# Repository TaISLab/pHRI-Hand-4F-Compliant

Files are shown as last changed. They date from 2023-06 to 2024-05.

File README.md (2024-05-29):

# pHRI-Hand-4F-Compliant

En este repositorio se encuentran los archivos relativos a la interacción fisica robot-humano. Por tanto, se encuentran ficheros de la garra subactuada de cuatro dedos con muelles en los eslabones

Overview of the gripper
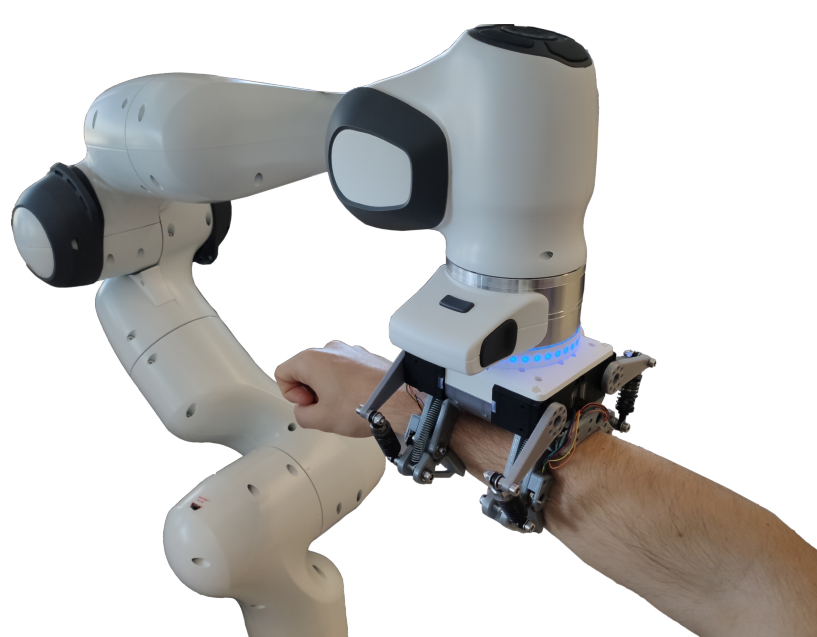
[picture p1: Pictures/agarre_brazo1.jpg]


Passive compliance
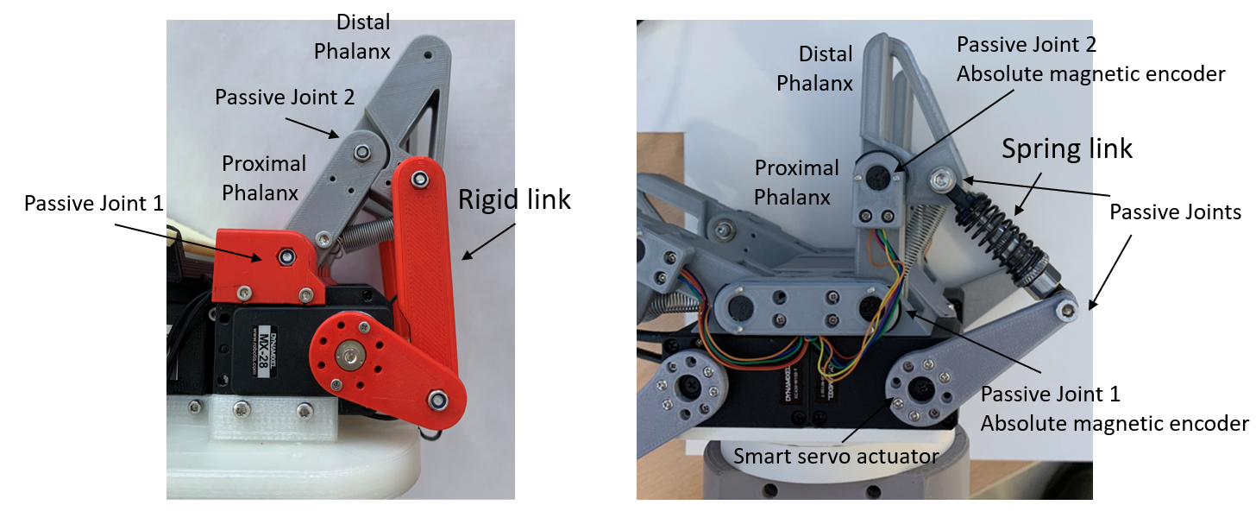
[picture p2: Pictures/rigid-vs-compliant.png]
Rigid vs flexible Links


También se encuentran los codigos fuente del control compartido.

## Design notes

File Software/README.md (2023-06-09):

# underactuated-gripper

En este repositorio se encuentran todos los ficheros relativos a la garra subactuada de cuatro dedos con eslabón elástico. El repositorio está organizado de la siguiente forma:

- **Carpeta arduino.** Contiene los codigos fuente de los dispositivos implicados en la garra. Contiene los scripts del sensor de fuerzas cilíndrico rojo basado en galgas extensiométricas y el sensor HX711 (Lectura\_hx711), y de control de la garra (lecturaMotorEncoder\_V8).

- **Carpeta Data.** Contiene los datos de los experimentos realizados con la garra. Los datos se encuentran separados por carpetas, atendiendo al tipo de experimento con el que se han obtenido.

- **Carpeta grippers\_conf.** Contiene los parametros de las garras subactuada de cuatro dedos y rolling fingers en formato JSON. Se pueden cargar desde la interfaz del robot para hacer el cambio de efector final. 

- **Carpeta ros.** Contiene el paquete ROS (version melodic) desarrollado para el control y la monitorización de la garra desde dicho OS. 

- **Carpeta scripts.** Contiene los programas de matlab para el computo del modelo kinetostatico de los dedos, así como los scripts para el procesamiento de los datos de los experimentos y su representación gráfica.

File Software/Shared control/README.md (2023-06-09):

# Requisitos del Shared control 

Para el funcionamiento del shared control es necesario el uso de la librería libfranka y un sistema operativo de tiempo real (en la página web de franka emika se explica como instalarlo, añadir enlace al tutorial), un robot franka emika (he implementado el control directamente sobre la API de este robot), el paquete matlogger para recopilación de datos (añadir link al repo de matlogger).

La carpeta franka\_ros contiene el paquete de ros de franka emika con todos los controladores que he desarrollado (es la versión del robot FR3), mas concretamente es dentro de la carpeta "franka\_example\_controllers" donde se encuentran todos los controladores que he desarrollado (a parte de los que vienen en el paquete por defecto). Es importante que el paquete "subact\_gripper" se encuentre en el mismo workspace de ros que el paquete "franka\_ros", ya que se requiere el uso de la garra en algunos controladores.

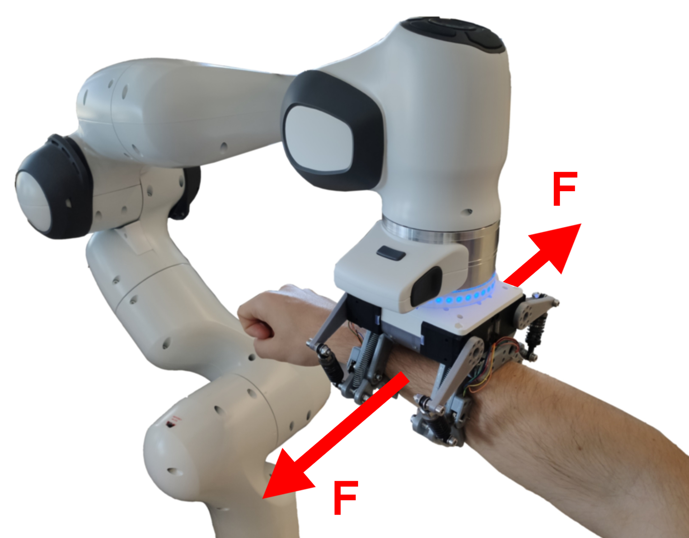
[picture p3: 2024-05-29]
Pictures/agarre_brazo1_F.jpg

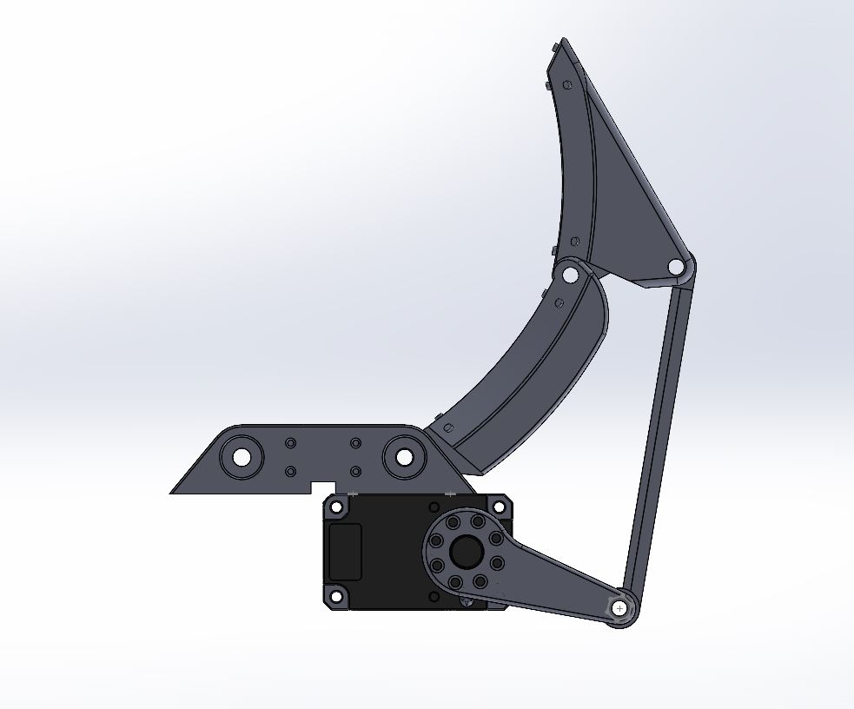
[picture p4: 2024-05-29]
CAD/Mano2.JPG

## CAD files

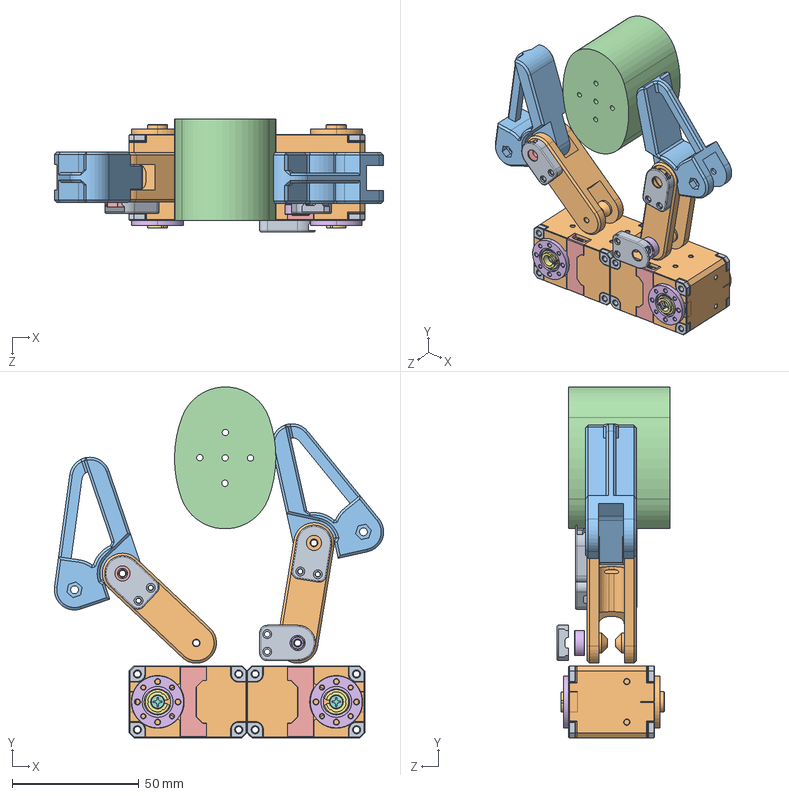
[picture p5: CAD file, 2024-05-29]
CAD/mano2.SLDASM
130.0 x 138.5 x 44.5 mm
potBASE x 3
DC11_A01_DUMMY.stp x 2
DX124_SCREW-COVER.stp x 2
B3B-EH.stp x 4
DC11_A01_CASE_CVR_DUMMY.stp x 2
DC11_A01_IDLER_DUMMY.stp x 2
DC11_A01_IDLER_CAP_DUMMY.stp x 2
DC11_A01_IDLER_SCREW.stp x 2
DC11_A01_SPACER_DUMMY.stp x 16
Palo1 x 2
pico20-ligero x 2
potenciometro
3x10x4 x 2

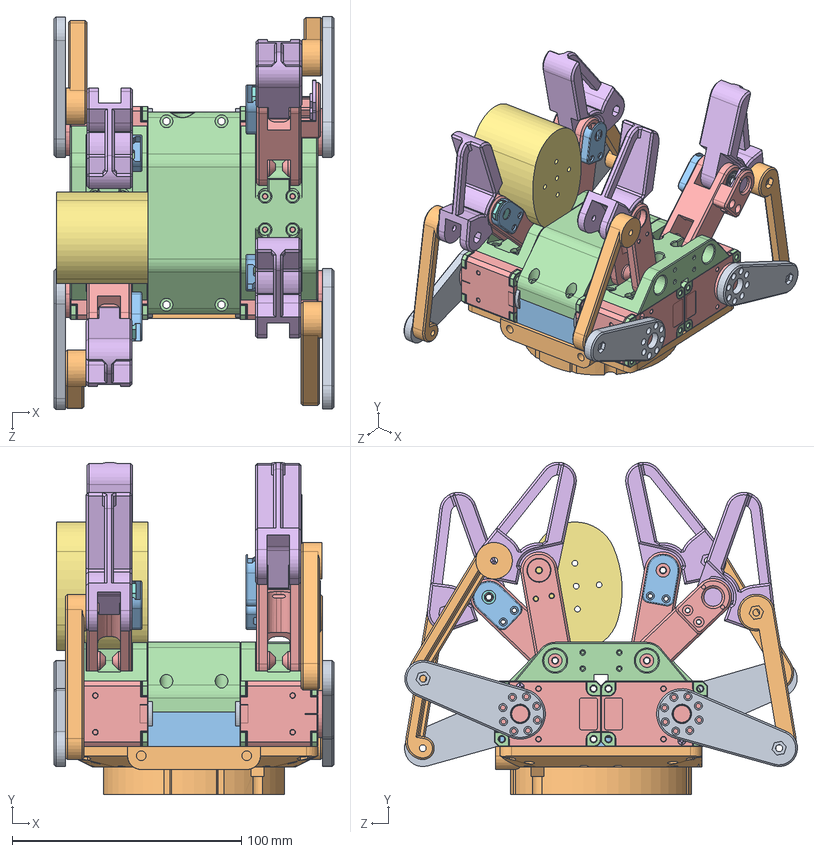
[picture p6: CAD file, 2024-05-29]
CAD/mano4.SLDASM
122.0 x 145.0 x 171.4 mm
biela servo 45 x 4
Palo2 x 4
potBASE x 6
base4 x 2
DC11_A01_DUMMY.stp x 4
DX124_SCREW-COVER.stp x 4
B3B-EH.stp x 8
DC11_A01_CASE_CVR_DUMMY.stp x 4
DC11_A01_IDLER_DUMMY.stp x 4
DC11_A01_IDLER_CAP_DUMMY.stp x 4
DC11_A01_IDLER_SCREW.stp x 4
DC11_A01_SPACER_DUMMY.stp x 32
Palo1 x 4
pico20-ligero x 4
potenciometro x 2
3x10x4 x 4
base-robot-4
module control
module-chepa
soporteencodersimple
as5048a

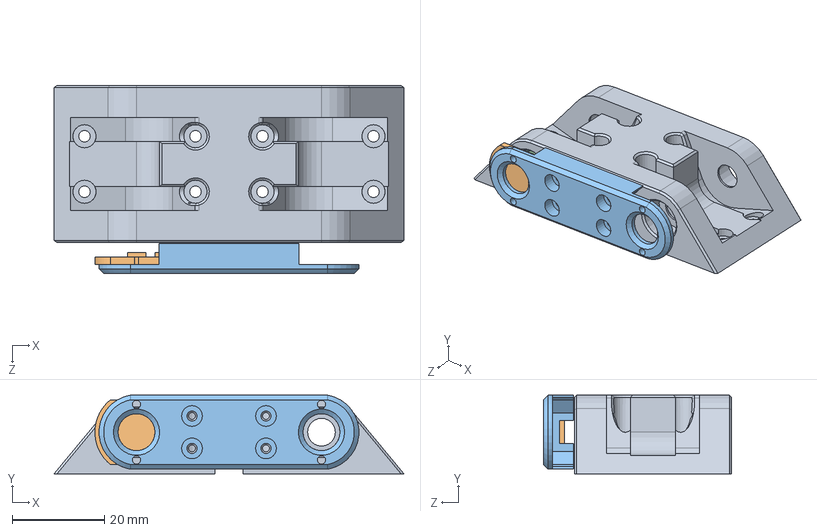
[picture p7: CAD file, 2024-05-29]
CAD/ensamblebasedosdedos.SLDASM
75.7 x 17.0 x 40.7 mm
base4
as5048a
soporteencoder
3x10x4

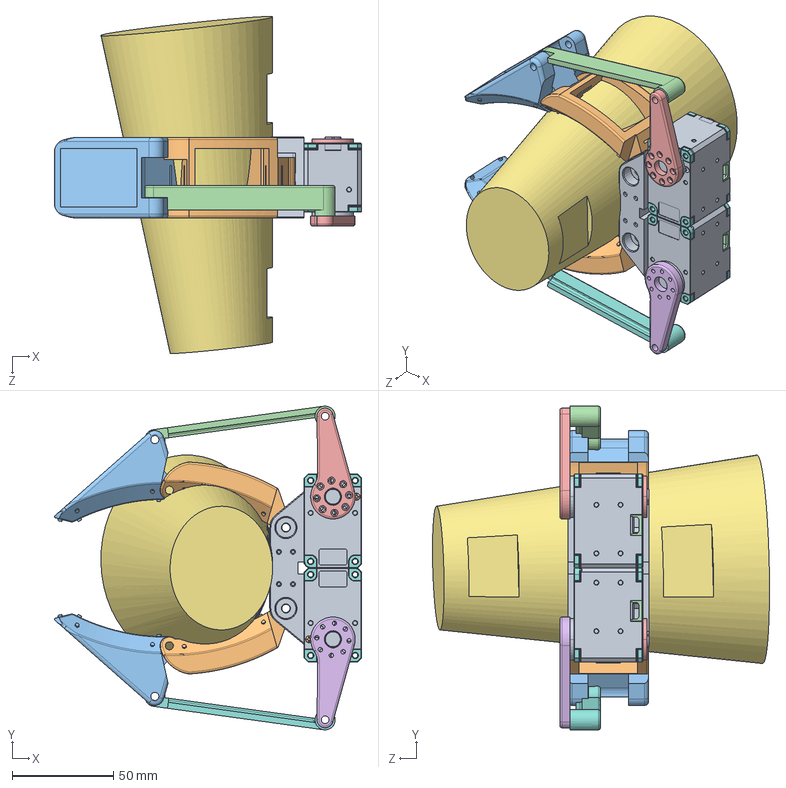
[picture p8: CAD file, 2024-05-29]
CAD/Mano2_mod - antebrazo.SLDASM
152.1 x 160.1 x 166.7 mm
DC11_A01_DUMMY.stp x 2
DX124_SCREW-COVER.stp x 2
B3B-EH.stp x 4
DC11_A01_CASE_CVR_DUMMY.stp x 2
DC11_A01_IDLER_DUMMY.stp x 2
DC11_A01_IDLER_CAP_DUMMY.stp x 2
DC11_A01_IDLER_SCREW.stp x 2
DC11_A01_SPACER_DUMMY.stp x 16
base4_mod
phalanx1_v8 x 2
phalanx2_v7 x 2
Palo2 85mm
Biela Servo 40 mm
Biela Servo 40 mm - left
Modelo_brazo_notwist
Palo2 85mm - left

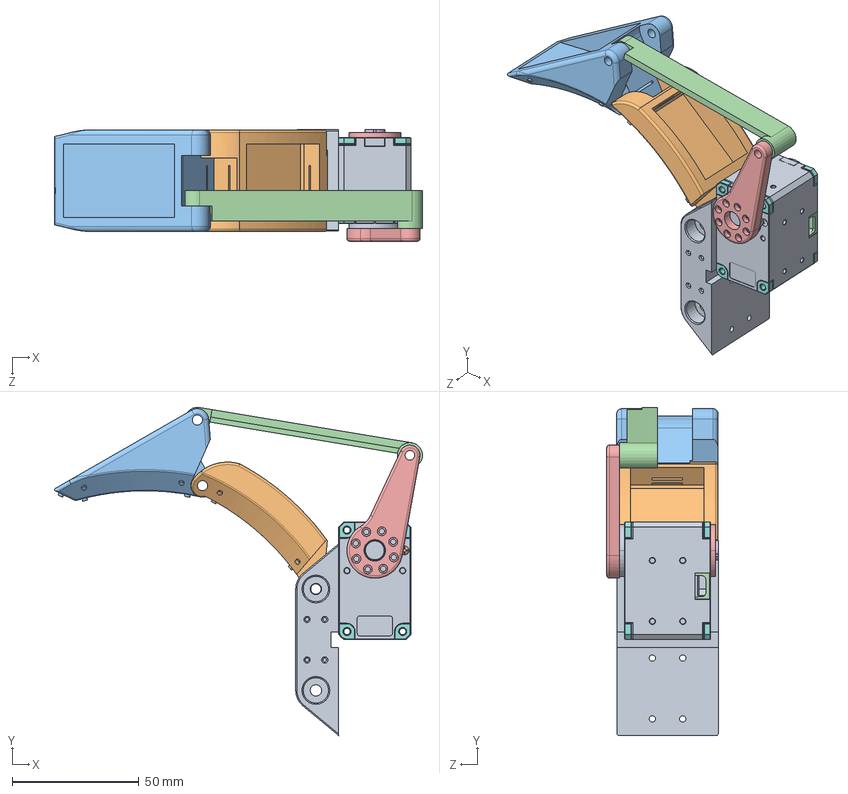
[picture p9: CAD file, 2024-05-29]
CAD/Mano2_mod.SLDASM
145.2 x 129.5 x 44.0 mm
DC11_A01_DUMMY.stp
DX124_SCREW-COVER.stp
B3B-EH.stp x 2
DC11_A01_CASE_CVR_DUMMY.stp
DC11_A01_IDLER_DUMMY.stp
DC11_A01_IDLER_CAP_DUMMY.stp
DC11_A01_IDLER_SCREW.stp
DC11_A01_SPACER_DUMMY.stp x 8
base4_mod
phalanx1_v8
phalanx2_v7
Palo2 85mm
Biela Servo 40 mm

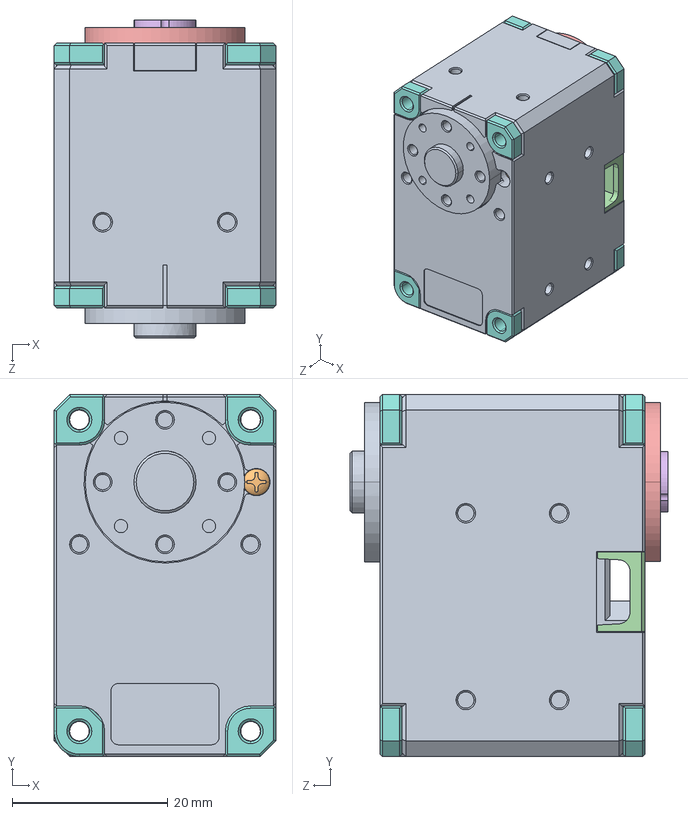
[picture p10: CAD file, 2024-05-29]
CAD/XL-430_new.SLDASM
28.5 x 46.5 x 40.9 mm
DC11_A01_DUMMY.stp
DX124_SCREW-COVER.stp
B3B-EH.stp x 2
DC11_A01_CASE_CVR_DUMMY.stp
DC11_A01_IDLER_DUMMY.stp
DC11_A01_IDLER_CAP_DUMMY.stp
DC11_A01_IDLER_SCREW.stp
DC11_A01_SPACER_DUMMY.stp x 8

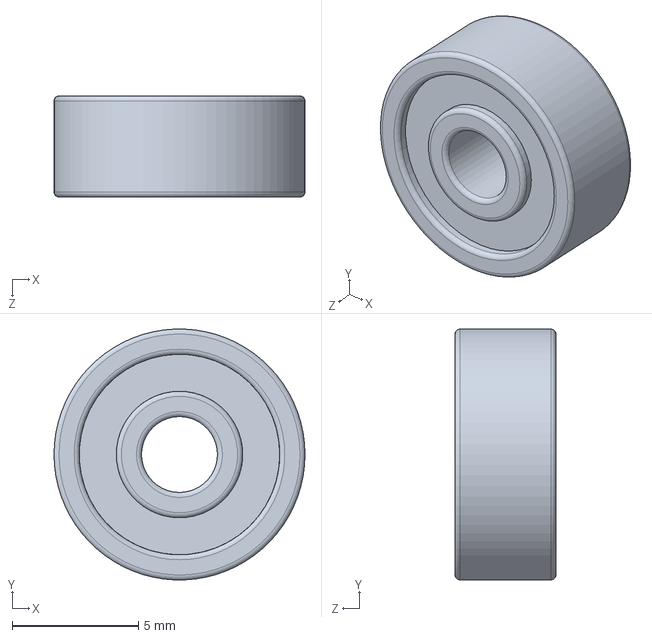
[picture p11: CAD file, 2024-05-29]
CAD/bearings/3x10x4.SLDPRT
9.93 x 9.92 x 4.00 mm

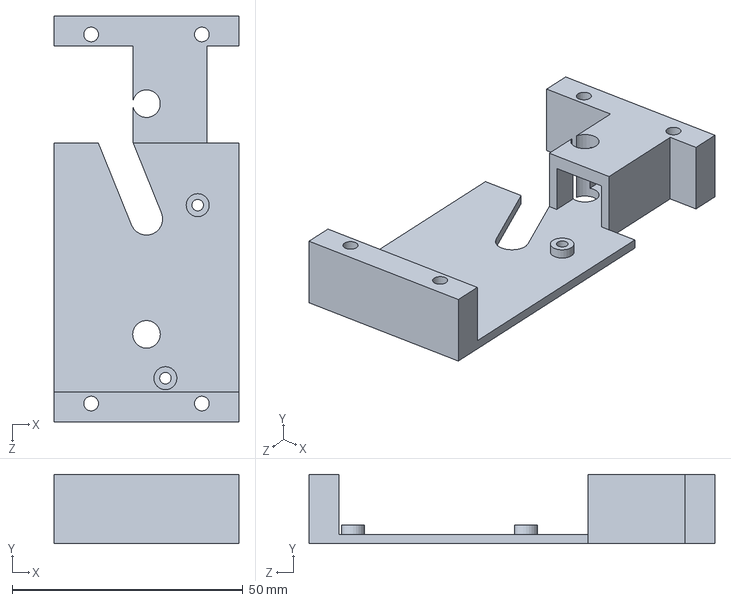
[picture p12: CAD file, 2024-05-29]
CAD/module control.SLDPRT
40.0 x 15.0 x 88.0 mm

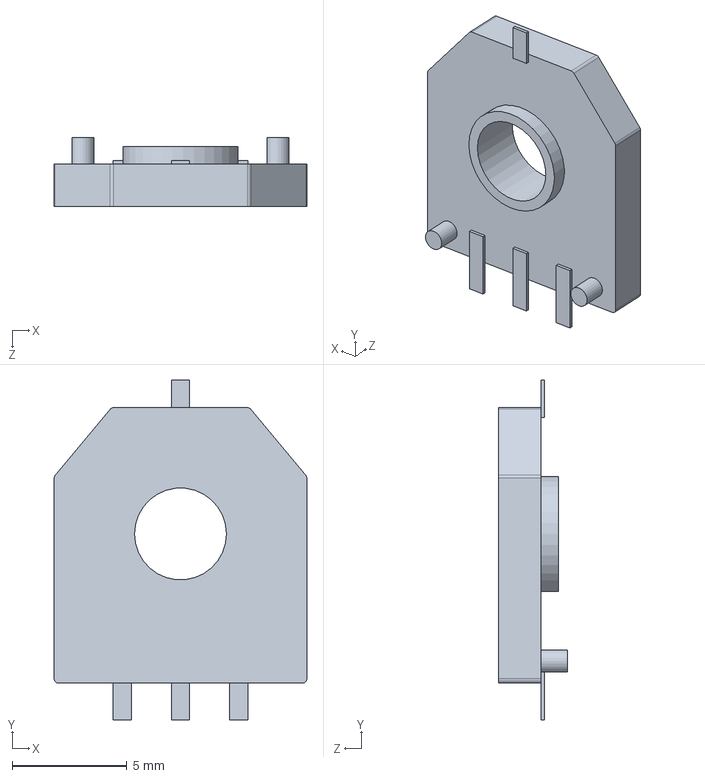
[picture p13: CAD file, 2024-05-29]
CAD/potentiometers/potenciometro.SLDPRT
11.0 x 14.8 x 3.01 mm

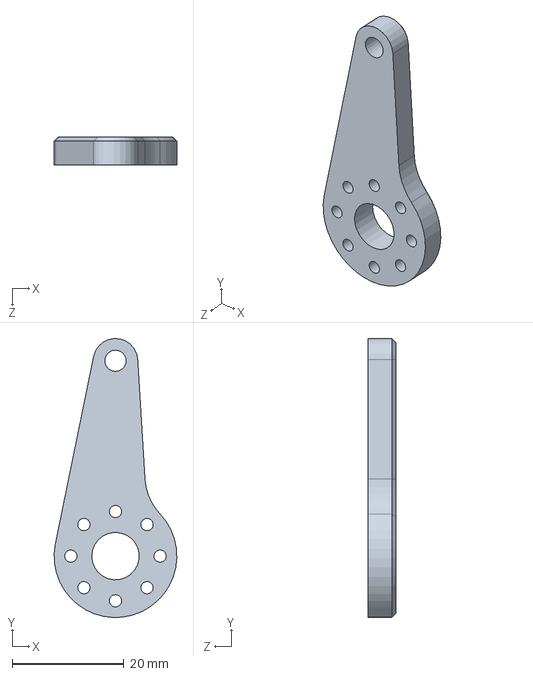
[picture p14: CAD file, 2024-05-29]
CAD/biela servo 2-1.SLDPRT
22.0 x 50.0 x 5.00 mm

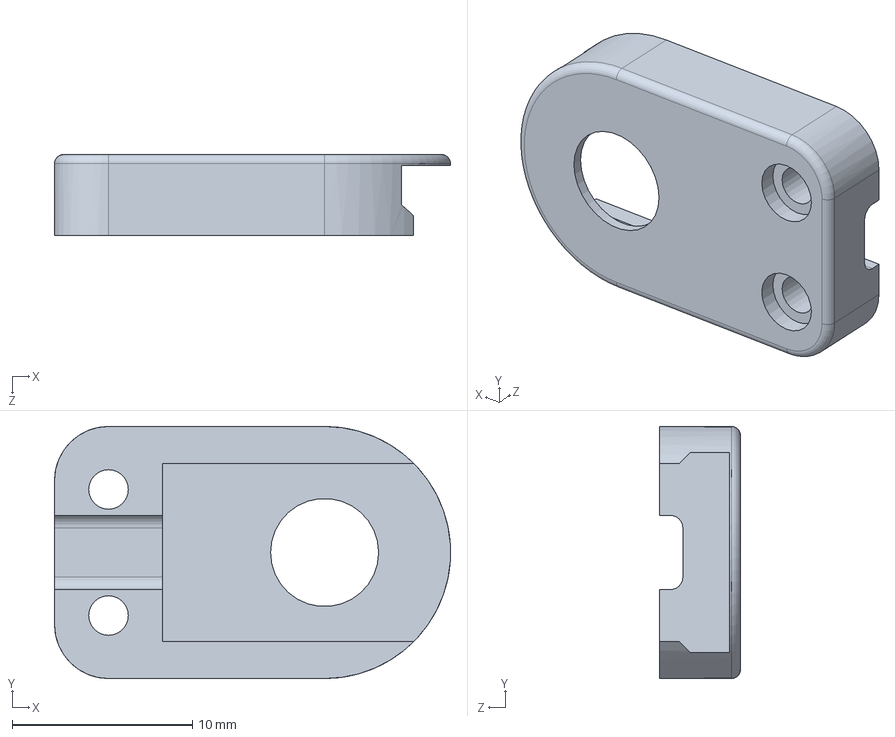
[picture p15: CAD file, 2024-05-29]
CAD/potentiometers/potBASE.SLDPRT
22.0 x 14.0 x 4.50 mm

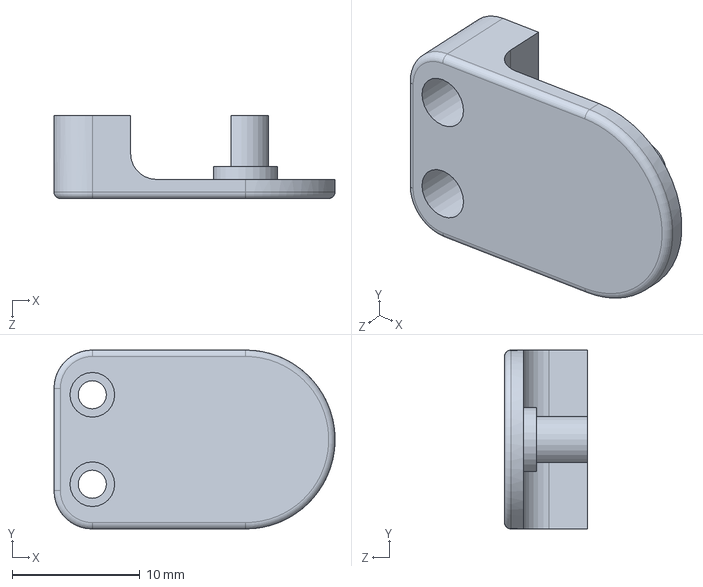
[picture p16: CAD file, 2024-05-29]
CAD/potentiometers/potlid.SLDPRT
22.0 x 14.0 x 6.50 mm

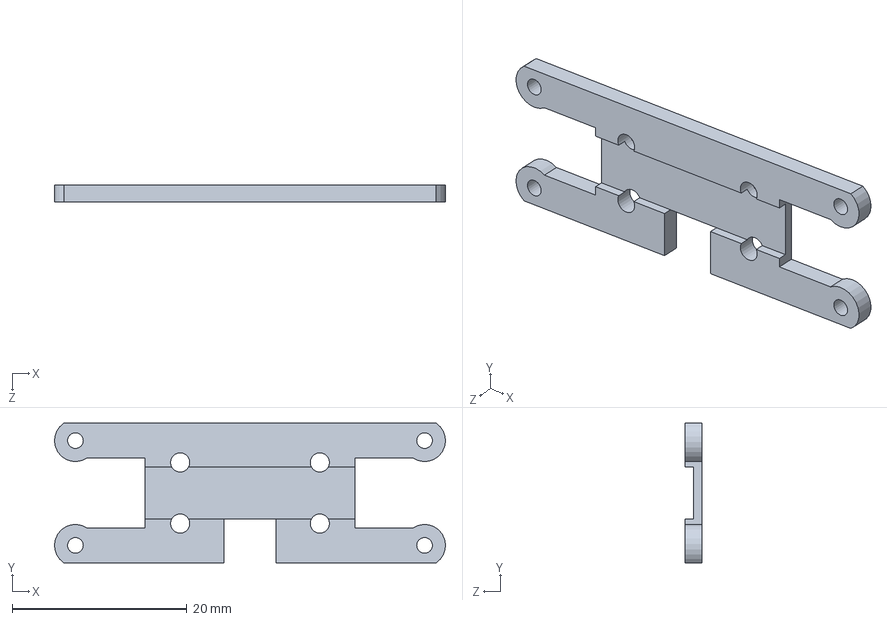
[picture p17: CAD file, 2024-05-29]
CAD/soporteencoder2.SLDPRT
44.8 x 16.0 x 2.00 mm

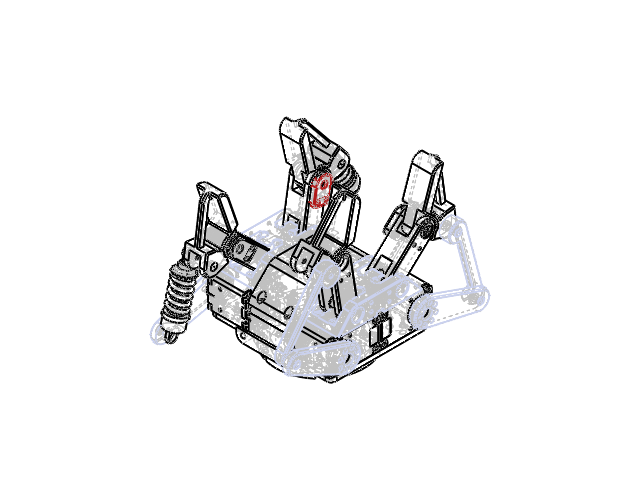
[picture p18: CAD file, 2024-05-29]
CAD/mano4-muelle.SLDASM
biela servo 50 x 4
potBASE x 6
base4 x 2
Palo1 x 4
pico20-ligero x 4
potenciometro x 2
3x10x4 x 4
base-robot-4
module control
module-chepa
Amortecedor (PRONTO) x 2

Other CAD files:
CAD/amortiguador/Revo Shock Assembly.sldasm
CAD/amortiguador/REvo Shock MountCap.sldprt
CAD/amortiguador/Revo Shock Rod.sldprt
CAD/amortiguador/Revo Shock Piston Valve.sldprt
CAD/Amortecedor (PRONTO).SLDDRW
CAD/Amortecedor (PRONTO).SLDPRT
CAD/Axis_4mm.SLDPRT
CAD/Biela Servo 40 mm - left.SLDPRT
CAD/Biela Servo 40 mm.SLDPRT
CAD/Modelo_brazo_notwist.SLDPRT
CAD/Palo1.SLDDRW
CAD/Palo1.SLDPRT
CAD/Palo1.STL
CAD/Palo2 85mm - left.SLDPRT
CAD/Palo2 85mm.SLDPRT
CAD/Palo2.SLDDRW
CAD/Palo2.SLDPRT
CAD/XL-430_new.SLDDRW
CAD/acopla-top.SLDPRT
CAD/amortiguador/REvo Shock Bump Stop.sldprt
CAD/amortiguador/Revo SPring.sldprt
CAD/amortiguador/Revo Shock Body.sldprt
CAD/amortiguador/Revo Shock Rod End.sldprt
CAD/amortiguador/Revo Shock Seal Cap.sldprt
CAD/amortiguador/Revo Shock Spring Adjustment Nut.sldprt
CAD/as5048a.SLDPRT
CAD/base-robot-4.SLDPRT
CAD/base-robot-4.STL
CAD/base-robot.SLDPRT
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

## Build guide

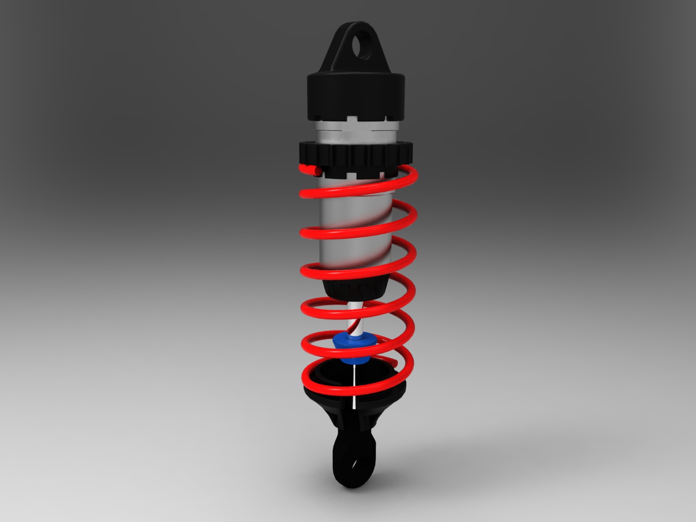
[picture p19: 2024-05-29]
CAD/amortiguador/Revo Shock Assembly.27.jpg

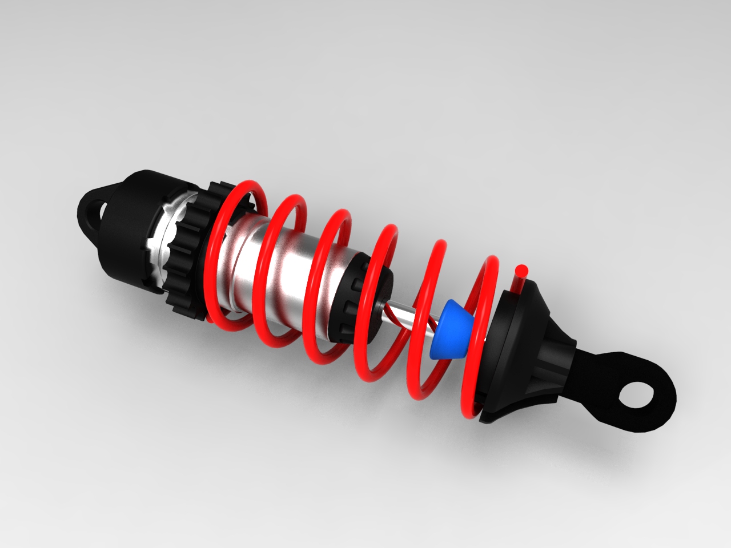
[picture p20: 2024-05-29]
CAD/amortiguador/Revo Shock Assembly.26.jpg

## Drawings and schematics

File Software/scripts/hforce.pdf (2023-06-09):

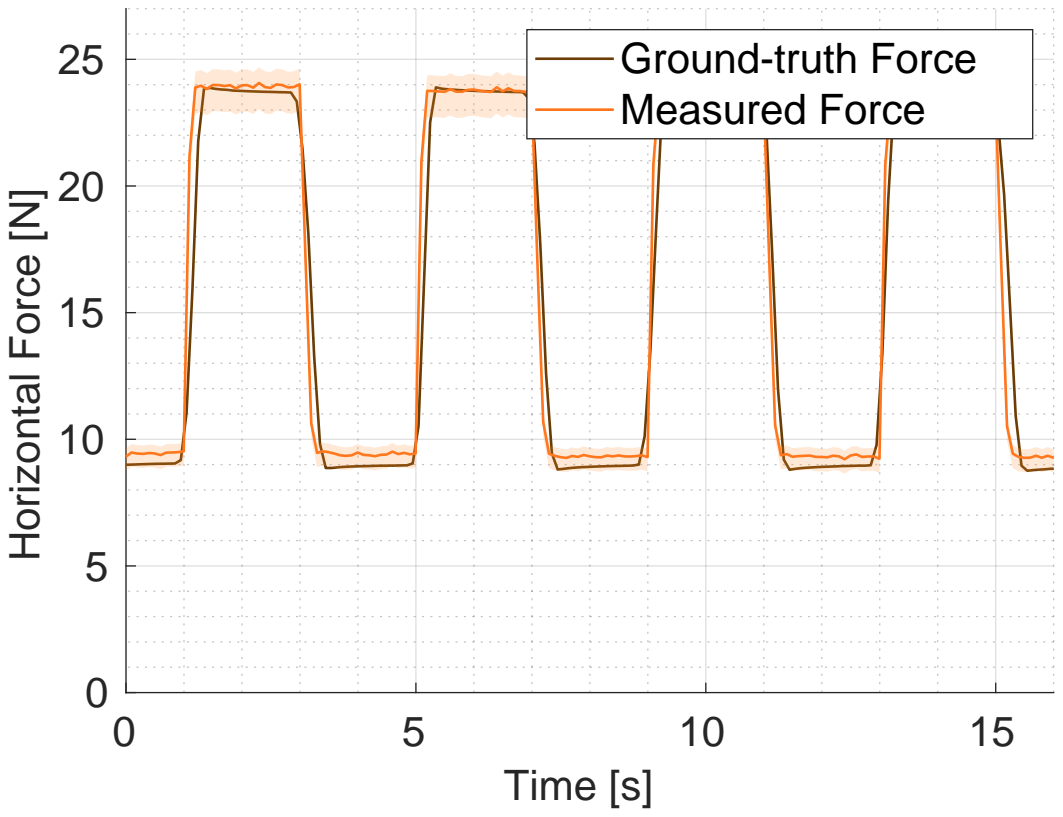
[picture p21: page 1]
Time [s]; Horizontal Force [N]

Ground-truth Force
Measured Force

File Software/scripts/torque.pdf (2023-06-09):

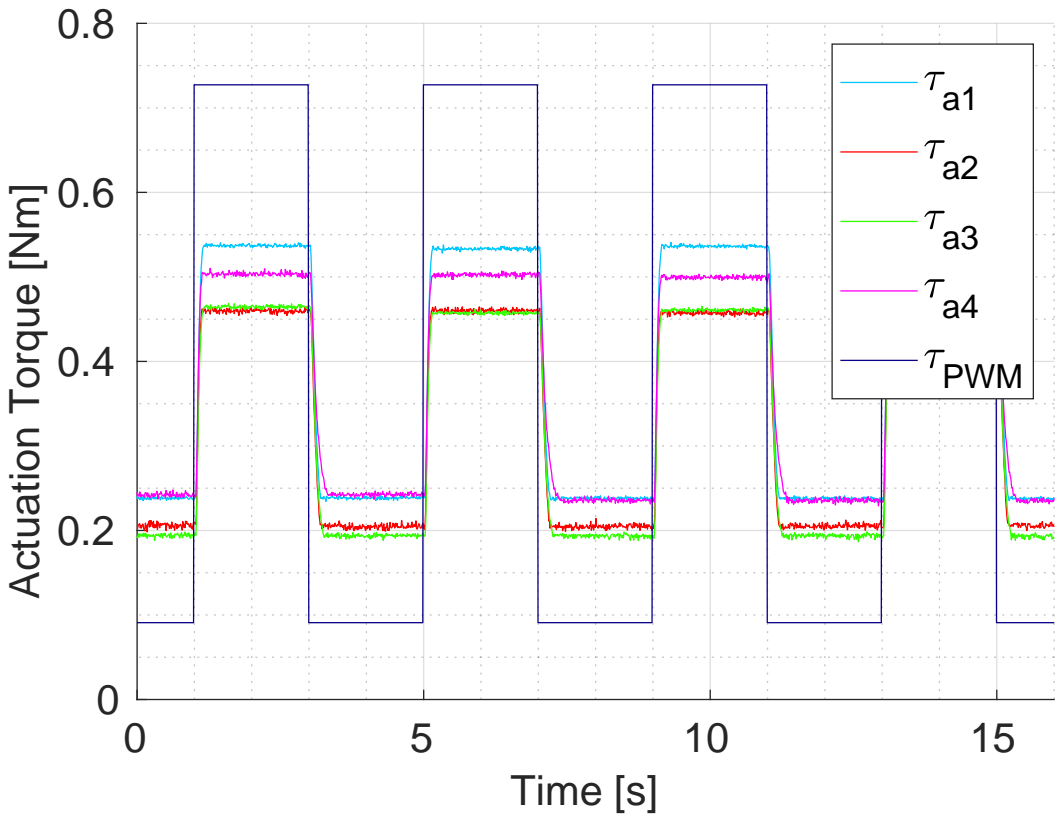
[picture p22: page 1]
Time [s]; PWM

a2
a3
a4

Actuation Torque [Nm]

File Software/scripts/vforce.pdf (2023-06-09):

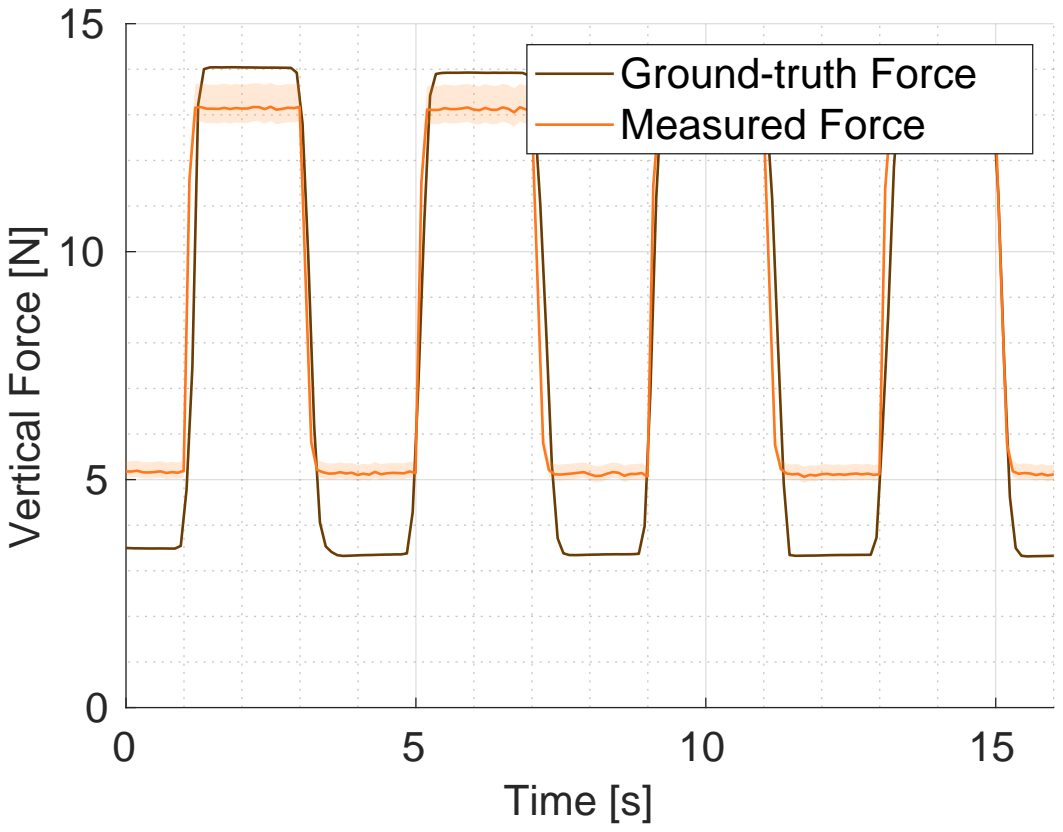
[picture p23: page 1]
Time [s]; Vertical Force [N]

Ground-truth Force
Measured Force

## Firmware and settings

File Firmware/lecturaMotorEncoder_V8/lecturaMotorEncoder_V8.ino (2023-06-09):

/***********************************************************************************
* LecturaMotorEncoder_V7
*   Programa de control y recogida de datos de la garra subactuada de cuatro dedos 
*   con encoders magnéticos en todas las articulaciones y función de apertura y cierre
*   a traves del puerto serie.
*   
*   ---CAMBIOS DE VERSION---
*     Implementacion de PI para control en par de los motores
*     Comandos a traves de UART en par y no en PWM
*   
*   pin 12 --  señal rgb
*   
*   27/04/2021 - 14:00
***********************************************************************************/

#include "AS5048A.h"
#include <Dynamixel2Arduino.h>
#include <Adafruit_NeoPixel.h>
#include <math.h>
#ifdef __AVR__
 #include <avr/power.h> // Required for 16 MHz Adafruit Trinket
#endif


#define PERIODO      10000       // Periodo 10 milisegundos
#define SYNC         22
#define DXL_SERIAL   Serial1
#define DEBUG_SERIAL Serial
#define DXL_ID_CNT   4        // numero de motores conectados
#define DEG_CONV     0.088    // factor de conversion de posicion en º/bit (motor)
#define RAW2DEG      0.022    // factor de conversion de posicion en º/bit (sensor)
#define CONTROL_P    90
#define CONTROL_I    10
#define CONTROL_D    0
#define LED_PIN      12
#define LED_COUNT    36
#define BRIGHTNESS   70
#define K_P

const uint8_t DXL_DIR_PIN = 8; //DYNAMIXEL Shield
//const uint8_t DXL_ID = 1;
//const float DXL_PROTOCOL_VERSION = 2.0;
const char CLOSE_COMMAND = 'c';  // Comando de control por puerto serie
const char OPEN_COMMAND = 'a';   // Comando de control por puerto serie
const char RELAX_COMMAND = 'r';  // Comando de control por puerto serie
const int N_SENSORES = 8;  // numero de AS5048A en daisy chain
// SYNC READ AND WRITE CONSTANTS
//const uint8_t DXL_ID_CNT = 4;
const uint8_t DXL_ID_LIST[DXL_ID_CNT] = {1, 2, 3, 4};
const uint16_t user_pkt_buf_cap = 128;
const int32_t ABRIR_POS[DXL_ID_CNT] = {150/DEG_CONV, 25/DEG_CONV, 240/DEG_CONV, 120/DEG_CONV};
//const int32_t CERRAR_POS[DXL_ID_CNT] = {40/DEG_CONV, 138/DEG_CONV, 130/DEG_CONV, 230/DEG_CONV};
int32_t CERRAR_PWM[DXL_ID_CNT] = {-250, 250, -250, 250};
//const int32_t ABRIR_PWM[DXL_ID_CNT] = {100, -100, 100, -100};
const int32_t ABRIR_PWM[DXL_ID_CNT] = {60, -60, 60, -60};

// constantes para la lectura del PWM por puerto serie
String str = "";
const char separator = ',';
const int pwmdataLength = 5;
int pwmdata[pwmdataLength];

// Factores de correcion para las medidas angulares
bool FIRST = true;
 float FCa[4] = {0,0,0,0}; //{-7.43, -7.52, -5.94, -7.35};
 float FC1[4] = {0,0,0,0}; // {3.54, 2.91, 3.04, 2.15};
 float FC2[4] = {0,0,0,0}; // {-0.5, -0.5, -0.6, 0.7};

const uint16_t SR_START_ADDR =132; // <-- Present position | 126 <-- present load | 124 <-- present pwm
const uint16_t SR_ADDR_LEN = 4; // <-- tamaño del buffer pos | 2+4+4 <-- load+vel+pos | 2+2+4+4 <-- pwm+load+vel+pos
const uint16_t SW_START_ADDR = 100; // Goal PWM | 116<-- Goal position
const uint16_t SW_ADDR_LEN = 2;

// Definicion de structs
typedef struct sr_data{
  // // int16_t present_pwm;
  //int16_t present_current;
  //int32_t present_velocity;
  int32_t present_position;
} __attribute__((packed)) sr_data_t;
typedef struct sw_data{
  int32_t goal_position;
} __attribute__((packed)) sw_data_t;


// Variables globales
int cerrada=0;      // estado de la pinza
uint32_t tiempo,tiemposiguiente,tiempoinicial;  // Variables de control del bucle
// SYNC READ AND WRITE VARIABLES
uint8_t user_pkt_buf[user_pkt_buf_cap];
sr_data_t sr_data[DXL_ID_CNT];  // sync read
DYNAMIXEL::InfoSyncReadInst_t sr_infos;
DYNAMIXEL::XELInfoSyncRead_t info_xels_sr[DXL_ID_CNT];
sw_data_t sw_data[DXL_ID_CNT];  // sync write
DYNAMIXEL::InfoSyncWriteInst_t sw_infos;
DYNAMIXEL::XELInfoSyncWrite_t info_xels_sw[DXL_ID_CNT];

// Prototipos de funciones
void modo(int id);
void calibracion();
void abrir();
void cerrar();
void relax();
void colorSet(uint32_t color);

// Declaracion de clases
Dynamixel2Arduino dxl(DXL_SERIAL, DXL_DIR_PIN);
AS5048A angleSensor(30);
Adafruit_NeoPixel strip(LED_COUNT, LED_PIN, NEO_GRB + NEO_KHZ800);
// Argument 1 = Number of pixels in NeoPixel strip
// Argument 2 = Arduino pin number (most are valid)
// Argument 3 = Pixel type flags, add together as needed:
//   NEO_KHZ800  800 KHz bitstream (most NeoPixel products w/WS2812 LEDs)
//   NEO_KHZ400  400 KHz (classic 'v1' (not v2) FLORA pixels, WS2811 drivers)
//   NEO_GRB     Pixels are wired for GRB bitstream (most NeoPixel products)
//   NEO_RGB     Pixels are wired for RGB bitstream (v1 FLORA pixels, not v2)
//   NEO_RGBW    Pixels are wired for RGBW bitstream (NeoPixel RGBW products)


//This namespace is required to use Control table item names
using namespace ControlTableItem;



/***********************************************************************************
 * Funcion Setup
 ***********************************************************************************/
void setup()
{
  uint8_t i;

  //cli();
  //bitSet(UCSR1A, U2X1); // 
  bitClear(UCSR1A, U2X1); // Poner el bit U2X1 del reg. UCSR1A a 0 para mayor fiabilidad de la uart
  
  // Use UART port of DYNAMIXEL Shield to debug.
  DEBUG_SERIAL.begin(500000);
  dxl.begin(1000000); // dxl.begin(2000000);

  angleSensor.init();
  // Calibrar
  for(i=0; i<DXL_ID_CNT; i++){
    dxl.torqueOff(DXL_ID_LIST[i]);
    
    dxl.setOperatingMode(DXL_ID_LIST[i], OP_POSITION);
    dxl.setGoalCurrent(DXL_ID_LIST[i],150);
    dxl.setGoalPWM(DXL_ID_LIST[i],800);
    dxl.writeControlTableItem(POSITION_P_GAIN, DXL_ID_LIST[i], CONTROL_P);    // P
    dxl.writeControlTableItem(POSITION_I_GAIN, DXL_ID_LIST[i], CONTROL_I);    // I
    dxl.writeControlTableItem(POSITION_D_GAIN, DXL_ID_LIST[i], CONTROL_D);    // D
    
    dxl.torqueOn(DXL_ID_LIST[i]);

    dxl.setGoalPosition(DXL_ID_LIST[i],90/DEG_CONV);
    
  }
  delay(2000);
  calibracion();
  //

  
  for(i=0; i<DXL_ID_CNT; i++){
    dxl.torqueOff(DXL_ID_LIST[i]);
    
    dxl.setOperatingMode(DXL_ID_LIST[i], OP_PWM);
    dxl.setGoalPWM(DXL_ID_LIST[i],0);
    
    dxl.torqueOn(DXL_ID_LIST[i]);
  }
  
  // Fill the members of structure to syncRead using external user packet buffer
  sr_infos.packet.p_buf = user_pkt_buf;
  sr_infos.packet.buf_capacity = user_pkt_buf_cap;
  sr_infos.packet.is_completed = false;
  sr_infos.addr = SR_START_ADDR;
  sr_infos.addr_length = SR_ADDR_LEN;
  sr_infos.p_xels = info_xels_sr;
  sr_infos.xel_count = 0;  

  for(i=0; i<DXL_ID_CNT; i++){
    info_xels_sr[i].id = DXL_ID_LIST[i];
    info_xels_sr[i].p_recv_buf = (uint8_t*)&sr_data[i];
    sr_infos.xel_count++;
  }
  sr_infos.is_info_changed = true;


  // Fill the members of structure to syncWrite using internal packet buffer
  sw_infos.packet.p_buf = nullptr;
  sw_infos.packet.is_completed = false;
  sw_infos.addr = SW_START_ADDR;
  sw_infos.addr_length = SW_ADDR_LEN;
  sw_infos.p_xels = info_xels_sw;
  sw_infos.xel_count = 0;

  for(i=0; i<DXL_ID_CNT; i++){
    // Llenar el bufer de posiciones objetivo
    sw_data[i].goal_position = ABRIR_PWM[i];
  
    info_xels_sw[i].id = DXL_ID_LIST[i];
    info_xels_sw[i].p_data = (uint8_t*)&sw_data[i].goal_position;
    sw_infos.xel_count++;
  }
  sw_infos.is_info_changed = true;


  dxl.syncWrite(&sw_infos); // enviar posiciones [ABRIR]

  
  strip.begin();           // INITIALIZE NeoPixel strip object (REQUIRED)
  strip.show();            // Turn OFF all pixels ASAP
  strip.setBrightness(BRIGHTNESS); // Set BRIGHTNESS to about 1/5 (max = 255)
  
  //uint32_t color = strip.Color(0,0,255); // azul
  //DEBUG_SERIAL.println(color);
  colorSet(strip.Color(0,0,250));
  
  delay(3000);
  
  tiempo=micros();
  tiempoinicial=tiempo;  
  tiemposiguiente=tiempo;
}

/***********************************************************************************
 * Funcion Loop 
 ***********************************************************************************/
void loop()
{
  uint8_t i, recv_cnt;
  char command;
  bool once = true;
  uint32_t tsr;
  String opt;

  //do {
  if(tiempo<tiemposiguiente){
    // La lectura sincrona de los motores tarda 5 ms aprox. en realizarse
    // por lo que solo se puede hacer una en el tiempo de espera (10ms)
    // Si tsr es menor que 5 ms aprox. la lectura no es valida o no ha tenido lugar
    // y se debe repetir
    tiempo=micros();  
 // } while (tiempo<tiemposiguiente);
  }else{
    tiemposiguiente+=PERIODO;
    opt = "";

  
    //Leer encoders y mandar por puerto serial
    angleSensor.read_daisyChain(N_SENSORES); 
    
    // Angulos con respecto al mismo sistema de referencia
    opt += String(angleSensor.daisyReadings[0]*RAW2DEG + FC2[0])+"\t";
    opt += String(angleSensor.daisyReadings[1]*RAW2DEG + FC1[0])+"\t";
    opt += String(-angleSensor.daisyReadings[2]*RAW2DEG + FC2[1])+"\t";
    opt += String(-angleSensor.daisyReadings[3]*RAW2DEG + FC1[1])+"\t";
    opt += String(angleSensor.daisyReadings[4]*RAW2DEG + FC2[2])+"\t";
    opt += String(angleSensor.daisyReadings[5]*RAW2DEG + FC1[2])+"\t";
    opt += String(-angleSensor.daisyReadings[6]*RAW2DEG + FC2[3])+"\t";
    opt += String(-angleSensor.daisyReadings[7]*RAW2DEG + FC1[3])+"\t"; 

    //Leer motores y mandar por puerto serial
    recv_cnt = dxl.syncRead(&sr_infos);// Esta instruccion tarda 4.8 ms aprox.

    opt += String(-sr_data[0].present_position*DEG_CONV + FCa[0])+"\t";  // 101.29 -
    opt += String(sr_data[1].present_position*DEG_CONV + FCa[1])+"\t";  // 78.85 +
    opt += String(-sr_data[2].present_position*DEG_CONV + FCa[2])+"\t";  // 191.4 -
    opt += String(sr_data[3].present_position*DEG_CONV + FCa[3])+"\t";  // 169.66 +

  
    // End of line (DESDE AQUI)
    DEBUG_SERIAL.println(opt);  
  
    if(DEBUG_SERIAL.available()){
      str = Serial.readStringUntil('\n');
      for (int i = 0; i < pwmdataLength-1 ; i++)
      {
         int index = str.indexOf(separator);
         pwmdata[i] = str.substring(0, index).toInt();
         str = str.substring(index + 1);
      }
      // PWM positivos hacen que la garra cierre, PWM negativos hacen que la garra abra
      CERRAR_PWM[0] = -1* pwmdata[0];  // Factor de correccion -1 (motor orientado en sentido inverso)
      CERRAR_PWM[1] = +1* pwmdata[1];  // Factor de correccion +1 (motor orientado en sentido directo)
      CERRAR_PWM[2] = -1* pwmdata[2];  // Factor de correccion -1 (motor orientado en sentido inverso)
      CERRAR_PWM[3] = +1* pwmdata[3];  // Factor de correccion +1 (motor orientado en sentido directo)
      cerrar();
    }
    // HASTAS AQUI tarda 1.1 ms aprox.


  //Serial.println(compresionMuelle(angleSensor.daisyReadings[1]*RAW2DEG + FC1[0], angleSensor.daisyReadings[0]*RAW2DEG + FC2[0], -sr_data[0].present_position*DEG_CONV + FCa[0]));
  } 
}


/***********************************************************************************
 * Funciones de control de los servos
 ***********************************************************************************/
void modo(int id)
{
  dxl.torqueOff(id);

  dxl.setOperatingMode(id, OP_EXTENDED_POSITION);

  dxl.setGoalCurrent(id,100);
  dxl.setGoalPWM(id,800);
 
  dxl.writeControlTableItem(POSITION_P_GAIN, id, 20);   // P
  dxl.writeControlTableItem(POSITION_I_GAIN, id, 5);    // I
  dxl.writeControlTableItem(POSITION_D_GAIN, id, 0);    // D

  dxl.torqueOn(id);
}

void calibracion(){
  angleSensor.read_daisyChain(N_SENSORES);
  
  FCa[0] = +90;
  FCa[1] = -90;
  FCa[2] = +90;
  FCa[3] = -90;

  FC1[0] = 61 -(angleSensor.daisyReadings[1]*RAW2DEG);
  FC1[1] = 61 -(-angleSensor.daisyReadings[3]*RAW2DEG);
  FC1[2] = 61 -(angleSensor.daisyReadings[5]*RAW2DEG);
  FC1[3] = 61 -(-angleSensor.daisyReadings[7]*RAW2DEG);

  FC2[0] = 0-(angleSensor.daisyReadings[0]*RAW2DEG);
  FC2[1] = 0-(-angleSensor.daisyReadings[2]*RAW2DEG);
  FC2[2] = 0-(angleSensor.daisyReadings[4]*RAW2DEG);
  FC2[3] = 0-(-angleSensor.daisyReadings[6]*RAW2DEG);
}


void abrir()
{
  sw_data[0].goal_position = ABRIR_PWM[0];
  sw_data[1].goal_position = ABRIR_PWM[1];
  sw_data[2].goal_position = ABRIR_PWM[2];
  sw_data[3].goal_position = ABRIR_PWM[3];
  sw_infos.is_info_changed = true;
  dxl.syncWrite(&sw_infos); // */ 

  cerrada=0;
}

void cerrar()
{
  sw_data[0].goal_position = CERRAR_PWM[0];
  sw_data[1].goal_position = CERRAR_PWM[1];
  sw_data[2].goal_position = CERRAR_PWM[2];
  sw_data[3].goal_position = CERRAR_PWM[3];
  sw_infos.is_info_changed = true;
  dxl.syncWrite(&sw_infos); // */
  
  cerrada=1;
}

void relax()
{
  sw_data[0].goal_position = 0;
  sw_data[1].goal_position = 0;
  sw_data[2].goal_position = 0;
  sw_data[3].goal_position = 0;
  sw_infos.is_info_changed = true;
  dxl.syncWrite(&sw_infos); // */
  
  cerrada=1;
}

float compresionMuelle(float theta1, float theta2, float thetaa){
  int a, b, c, d, e;
  float q1, q2, qa, p2x, p2y, p3x, p3y, c_prima, compresion, gamma;
  
  //longitudes de los eslabones del dedo
  a = 40; b = 20; c = 59.5; d = 50; e = 28;
  
  //calculo de los angulos en rad
  q1 = PI/180 * theta1;
  q2 = PI/180 * theta2;
  qa = PI/180 * thetaa;
  gamma = acos(15.4/e);
  
  //calculo de la compresion del muelle
  p2x = a*cos(q1) + b*cos(q1 + q2 - PI/2 );
  p2y = a*sin(q1) + b*sin(q1 + q2 - PI/2 );
  p3x = 15.4 + d*cos(qa); //p3x = e*cos(-gamma) + d*cos(qa);
  p3y = -22.4 + d*sin(qa); //p3y = e*sin(-gamma) + d*sin(qa);
  c_prima = sqrt(pow(p2x-p3x,2)+pow(p2y-p3y,2));
  /*DEBUG_SERIAL.print(p2x);
  DEBUG_SERIAL.print("  ");
  DEBUG_SERIAL.print(p2y);
  DEBUG_SERIAL.print("  ");
  DEBUG_SERIAL.print(p3x);
  DEBUG_SERIAL.print("  ");
  DEBUG_SERIAL.print(p3y);
  DEBUG_SERIAL.print("  ");*/
  compresion = c - c_prima;
  return compresion;
}


void colorSet(uint32_t color) {
  for(int i=0; i<strip.numPixels(); i++) { // For each pixel in strip...
    strip.setPixelColor(i, color);         //  Set pixel's color (in RAM)
    strip.show();                          //  Update strip to match
  }
}

/*   ALTERNATIVA AL SWITCH CASE
 
      if(command == CLOSE_COMMAND)
        cerrar();
      else if(command == OPEN_COMMAND)
        abrir();
      else if(command == RELAX_COMMAND)
        relax();
 */

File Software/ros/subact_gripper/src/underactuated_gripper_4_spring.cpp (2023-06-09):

/* Class implementation to interact with the 4 fingers 2 phalanges underactuated gripper with elastic link
    Date: 15-02-2022
    Author: Francisco J. Ruiz-Ruiz
*/

#include <subact_gripper/underactuated_gripper_4_spring.h>
#include <ros/ros.h>

#include <matlogger2/matlogger2.h>
#include <matlogger2/utils/mat_appender.h>




UnderactuatedGripper4Spring::UnderactuatedGripper4Spring(ros::NodeHandle* node_handle){
std::cout << "STARTING" << std::endl;
    // PUBLISHERS 
    garra_msg_pub_ = node_handle->advertise<subact_gripper::pwm_control>("/robot_subactuated_gripper/pwm", 1);
    interaction_forces_pub_ = node_handle->advertise<geometry_msgs::WrenchStamped>("/robot_subactuated_gripper/interaction_force", 1);
    // SUBSCRIBERS
    garra_state_sub_ = node_handle->subscribe("/robot_subactuated_gripper/gripper_state",1, &UnderactuatedGripper4Spring::gripper_state_callback, this);
    force_sensor_sub_ = node_handle->subscribe("/robot_subactuated_gripper/ground_truth_grasping_force",1, &UnderactuatedGripper4Spring::force_sensor_callback, this);

    franka_pose_sub = node_handle->subscribe("/robot_vel_ctrl/pose",1, &UnderactuatedGripper4Spring::fpose_callback, this);
    franka_vel_sub = node_handle->subscribe("/robot_vel_ctrl/velocity_filtered",1, &UnderactuatedGripper4Spring::fvelocity_callback, this);

//    ffranka_sub = node_handle->subscribe("/franka_state_controller/F_ext", 1, &UnderactuatedGripper4Spring::ffranka_callback, this);

    ffranka_for = node_handle->subscribe("/franka_state_controller/F_ext",1, &UnderactuatedGripper4Spring::ffranka_callback, this);


    // VARIABLES INITIALIZATION
    for(int i=0; i<4; i++){
        /*if (i<3){
            error_[i] = 0;
        }*/
        theta_a_[i] = 0;
        theta_1_[i] = 0;
        theta_2_[i] = 0;
        forces_1_x_[i] = 0;
        forces_2_x_[i] = 0;
        forces_1_z_[i] = 0;
        forces_2_z_[i] = 0;
    }

    grasp_force_.setZero();
    interaction_forces_.setZero();

    Kp_ << 55.0, 58.0, 58.0, 55.0; // kp = {36.5, 60.5, 40.5, 50.5}                             // <------------------
    Ki_ << 20.0, 22.0, 22.0, 20.0; // ki = {3.80, 6.80, 3.80, 4.80}  
    ts_ = 0.01;
    Kd_.setZero();
    pwm_saturation_ = 500;
    pid_pwm_.setZero();
    error_.setZero();
    

    a_ = 0.04;
    b_ = 0.02;
    psi_ = M_PI_2;
    contact_point1_ = 0.02;
    contact_point2_ = 0.02;
    gamma_ = 0.9879; // 56.6 degrees
    e_ = 0.028;
    d_ = 0.05;
    w_ = 0.01; // phalanx width
    D_ = 0.08;// distance between parallel fingers
    ks1_ = 60;
    ks2_ = 675;
    ls1r_ = 0.016; 
    ls2r_ = 0.057;

    tara_z_ = 0;
    tara_timer_ = 0;

    fsensor1_ = 0;
    fsensor2_ = 0;
    
    ffranka.setZero();

    std::cout << "----- CLASS INITIALIZED -----" << std::endl;

/*    // open port
    //const char[] port = "/dev/ttyUSB0";
    serial_port_ = open("/dev/ttyUSB0", O_RDWR);
    // check errors
    if(serial_port_ < 0) {
        std::cout << "Error " << errno << "opening /dev/ttyUSB0: " << strerror(errno) << std::endl;
    }

    if(tcgetattr(serial_port_, &tty_) != 0){
        std::cout << "Error " << errno << "from tcgetattr: " << strerror(errno) << std::endl;
    }

    // Configure serial port
    tty_.c_cflag &= ~PARENB; // clear parity bit
    tty_.c_cflag &= ~CSTOPB; // one stop bit (set this bit for two stop bits)
    tty_.c_cflag |= CS8; // messages of 8 bits per byte
    tty_.c_cflag &= ~CRTSCTS; // RTS/CTS hardware flow control
    tty_.c_cflag |= CREAD | CLOCAL; // Turn on read and ignore ctrl lines (clocal = 1)
    tty_.c_lflag = 0; // no signaling chars, no echo, no canonical processing
    /*tty_.c_lflag &= ~ICANON;
    tty_.c_lflag &= ~ECHO;
    tty_.c_lflag &= ~ECHOE;
    tty_.c_lflag &= ~ECHONL;
    tty_.c_lflag &= ~ISIG;*/
/*    tty_.c_iflag &= ~(IXON | IXOFF | IXANY); // Turn off software flow ctrl
    tty_.c_iflag &= ~(IGNBRK | BRKi_NT | PARMRK | ISTRIP | INLCR | IGNCR | ICRNL); //Disable any special handling of received bytes 
    tty_.c_oflag &= ~(OPOST | ONLCR);
    tty_.c_cc[VTIME] = 1; // Timeout of 0.1 seconds
    tty_.c_cc[VMIN] = 1; // Or read 1 bytes
    // set baudrate
    cfsetispeed(&tty_, B500000);
    cfsetospeed(&tty_, B500000);

    // save tty settings
    if(tcsetattr(serial_port_, TCSANOW, &tty_) != 0){
        std::cout << "Error " << errno << "from tcsetattr: " << strerror(errno) << std::endl;
    }
*/    
}

UnderactuatedGripper4Spring::~UnderactuatedGripper4Spring(){
    //close(serial_port_);
}

/*float* UnderactuatedGripper4Spring::getGripperState(){
    char msg_read[10];
    char buffer;
    int n = 0; int index = 0; int global_index = 0;
    bool tab_init = false;

    do {
        n = read(serial_port_, &buffer, 1);
        if(buffer != '\t'){
            //tab_init = false;
            msg_read[index] = buffer;
            index++;
        } else {
            index = 0;
            std::string data_s(msg_read);
            std::stringstream ss;
            ss << data_s;
            ss >> gripper_state_[global_index];
            global_index++;
            //gripper_state_[global_index] = std::stof(data_s);
        }

    }while(global_index < 12);//while(buffer != '\r' && n > 0);

    if(n<0){
        std::cout << "Error reading serial port, error code " << n << std::endl;
    }
    else{
        for(int i=0;i<12;i++){
            std::cout << gripper_state_[i] << "  "; 
        }
        std::cout << "indexes: " << index << std::endl;
    }
    return &gripper_state_;
}*/

void UnderactuatedGripper4Spring::gripper_state_callback(const subact_gripper::sub_gripper& msg){
    /*for(int i=0; i<3; i++){
        finger1[i] = msg.dedo_1[i];
        finger2[i] = msg.dedo_2[i];
        finger3[i] = msg.dedo_3[i];
        finger4[i] = msg.dedo_4[i];
    }*/
    theta_a_[0] = msg.dedo_1[0]; theta_a_[1] = msg.dedo_2[0]; theta_a_[2] = msg.dedo_3[0]; theta_a_[3] = msg.dedo_4[0];
    theta_1_[0] = msg.dedo_1[1]; theta_1_[1] = msg.dedo_2[1]; theta_1_[2] = msg.dedo_3[1]; theta_1_[3] = msg.dedo_4[1];
    theta_2_[0] = msg.dedo_1[2]; theta_2_[1] = msg.dedo_2[2]; theta_2_[2] = msg.dedo_3[2]; theta_2_[3] = msg.dedo_4[2];
    // Transform from deg to rad
    for(int i=0; i<4; i++){
        theta_a_[i] = theta_a_[i] * M_PI/180;
        theta_1_[i] = theta_1_[i] * M_PI/180;
        theta_2_[i] = theta_2_[i] * M_PI/180;
    }
     
}

void UnderactuatedGripper4Spring::force_sensor_callback(const subact_gripper::force_meas_dev& msg){
    fsensor1_ = msg.sensor1;
    fsensor2_ = msg.sensor2;
    //std::cout << "Sensor msg: " << fsensor1_ << "  " << fsensor2_ << std::endl;
}
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

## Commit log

2023-06-09 Añadidos los archivos relativos a la garra subactuada de 4 dedos
2023-06-09 Añadida descripcion a grosso modo de lo que va a contener el repositorio
2024-05-29 General rearrangement
    [Axis_4mm.SLDPRT, Biela Servo 40 mm - left.SLDPRT, Biela Servo 40 mm.SLDPRT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]
2024-05-29 More Basic components added to CAD
    [3x10x4.SLDPRT, Amortecedor (PRONTO).SLDDRW, Amortecedor (PRONTO).SLDPRT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]
